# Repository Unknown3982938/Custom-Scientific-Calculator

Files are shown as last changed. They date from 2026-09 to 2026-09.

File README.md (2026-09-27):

# Custom-Scientific-Calculator
An open-source custom scientific calculator based on an ESP32, featuring a dedicated keypad matrix, MCP23017 I/O expansion, ST7789 display, rechargeable Li-ion power system, and a custom PCB.

# Project Status
## Work-In-Progress (WIP)
The hardware is currently undergoing PCB and mechanical development. Firmware and enclosure designs are also under active development and may change as physical prototypes are assembled and tested.

# Features
- ESP32-based controller
- ST7789 Color TFT (2.8 inch)
- MCP23017 I/O Expander
- 45 key Physical key matrix (custom)
- SD card support(OPTIONAL)
- Scientific and mathematical functions
- Rechargeable battery
- Modular/Serviceable design (planned to make a compact version, consisting of SMTs instead of THTs)
- Custom PCB
- Custom enclosure

# Repository Contents
- HARDWARE/ - Schematic, BOM, and PCB layout
- FIRMWARE/ - Sketch Code and other software related contents
- CAD/ENCLOSURE/ - Enclosure and Mechanical CAD files
- Manufacturing/ - fabrication-ready manufacturing files
- REFERENCES - Additional materials and information (e.g. Simulations, tests, and additional datas)

# Hardware
The calculator uses a custom PCB designed specifically for the project. The hardware is still being refined and has not yet completed final physical validation.

# Firmware
Firmware development is currently in progress. The included firmware represents the current development state and is subject to change as the hardware is validated.

# CAD
The enclosure and other mechanical components are included as CAD files. These designs are still being refined alongside the PCB and physical prototype.

# Goals
The goal is to create a functional, portable scientific calculator while gaining practical experience in:
- PCB design
- Embedded programming
- Human-machine interfaces
- Power management
- Mechanical design
- Electronics Manufacturing

---

The project is being developed incrementally, with hardware and software tested as each subsystem is completed.

ova
schem
Screenshot from 2026-09-11 13-05-26

---

# Socials:
(for other projects that is currently independently developed)

- https://tiktok.com/@philie_imation_001 (TIKTOK account)
- (some are set to private for now)

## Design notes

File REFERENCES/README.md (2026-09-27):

# REFERENCES:
## Circuit simulation:
- https://app.cirkitdesigner.com/project/ea1d36da-37de-4177-8c43-86d26a5ac79b (unfinished)

## Keymaps
- (TBA)

## GUI design
- (TBA)

---

TikTok acc: https://tiktok.com/@philie_imation_001 (this is where I often share my projects)

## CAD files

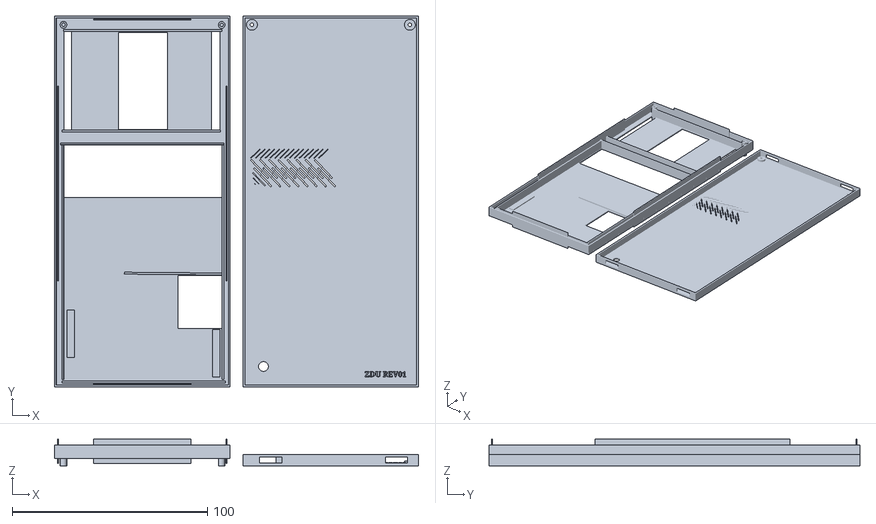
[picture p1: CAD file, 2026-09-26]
CAD/ENCLOSURE/custom cal enclosure(bottom)(1).stl
186.6 x 190.0 x 13.8

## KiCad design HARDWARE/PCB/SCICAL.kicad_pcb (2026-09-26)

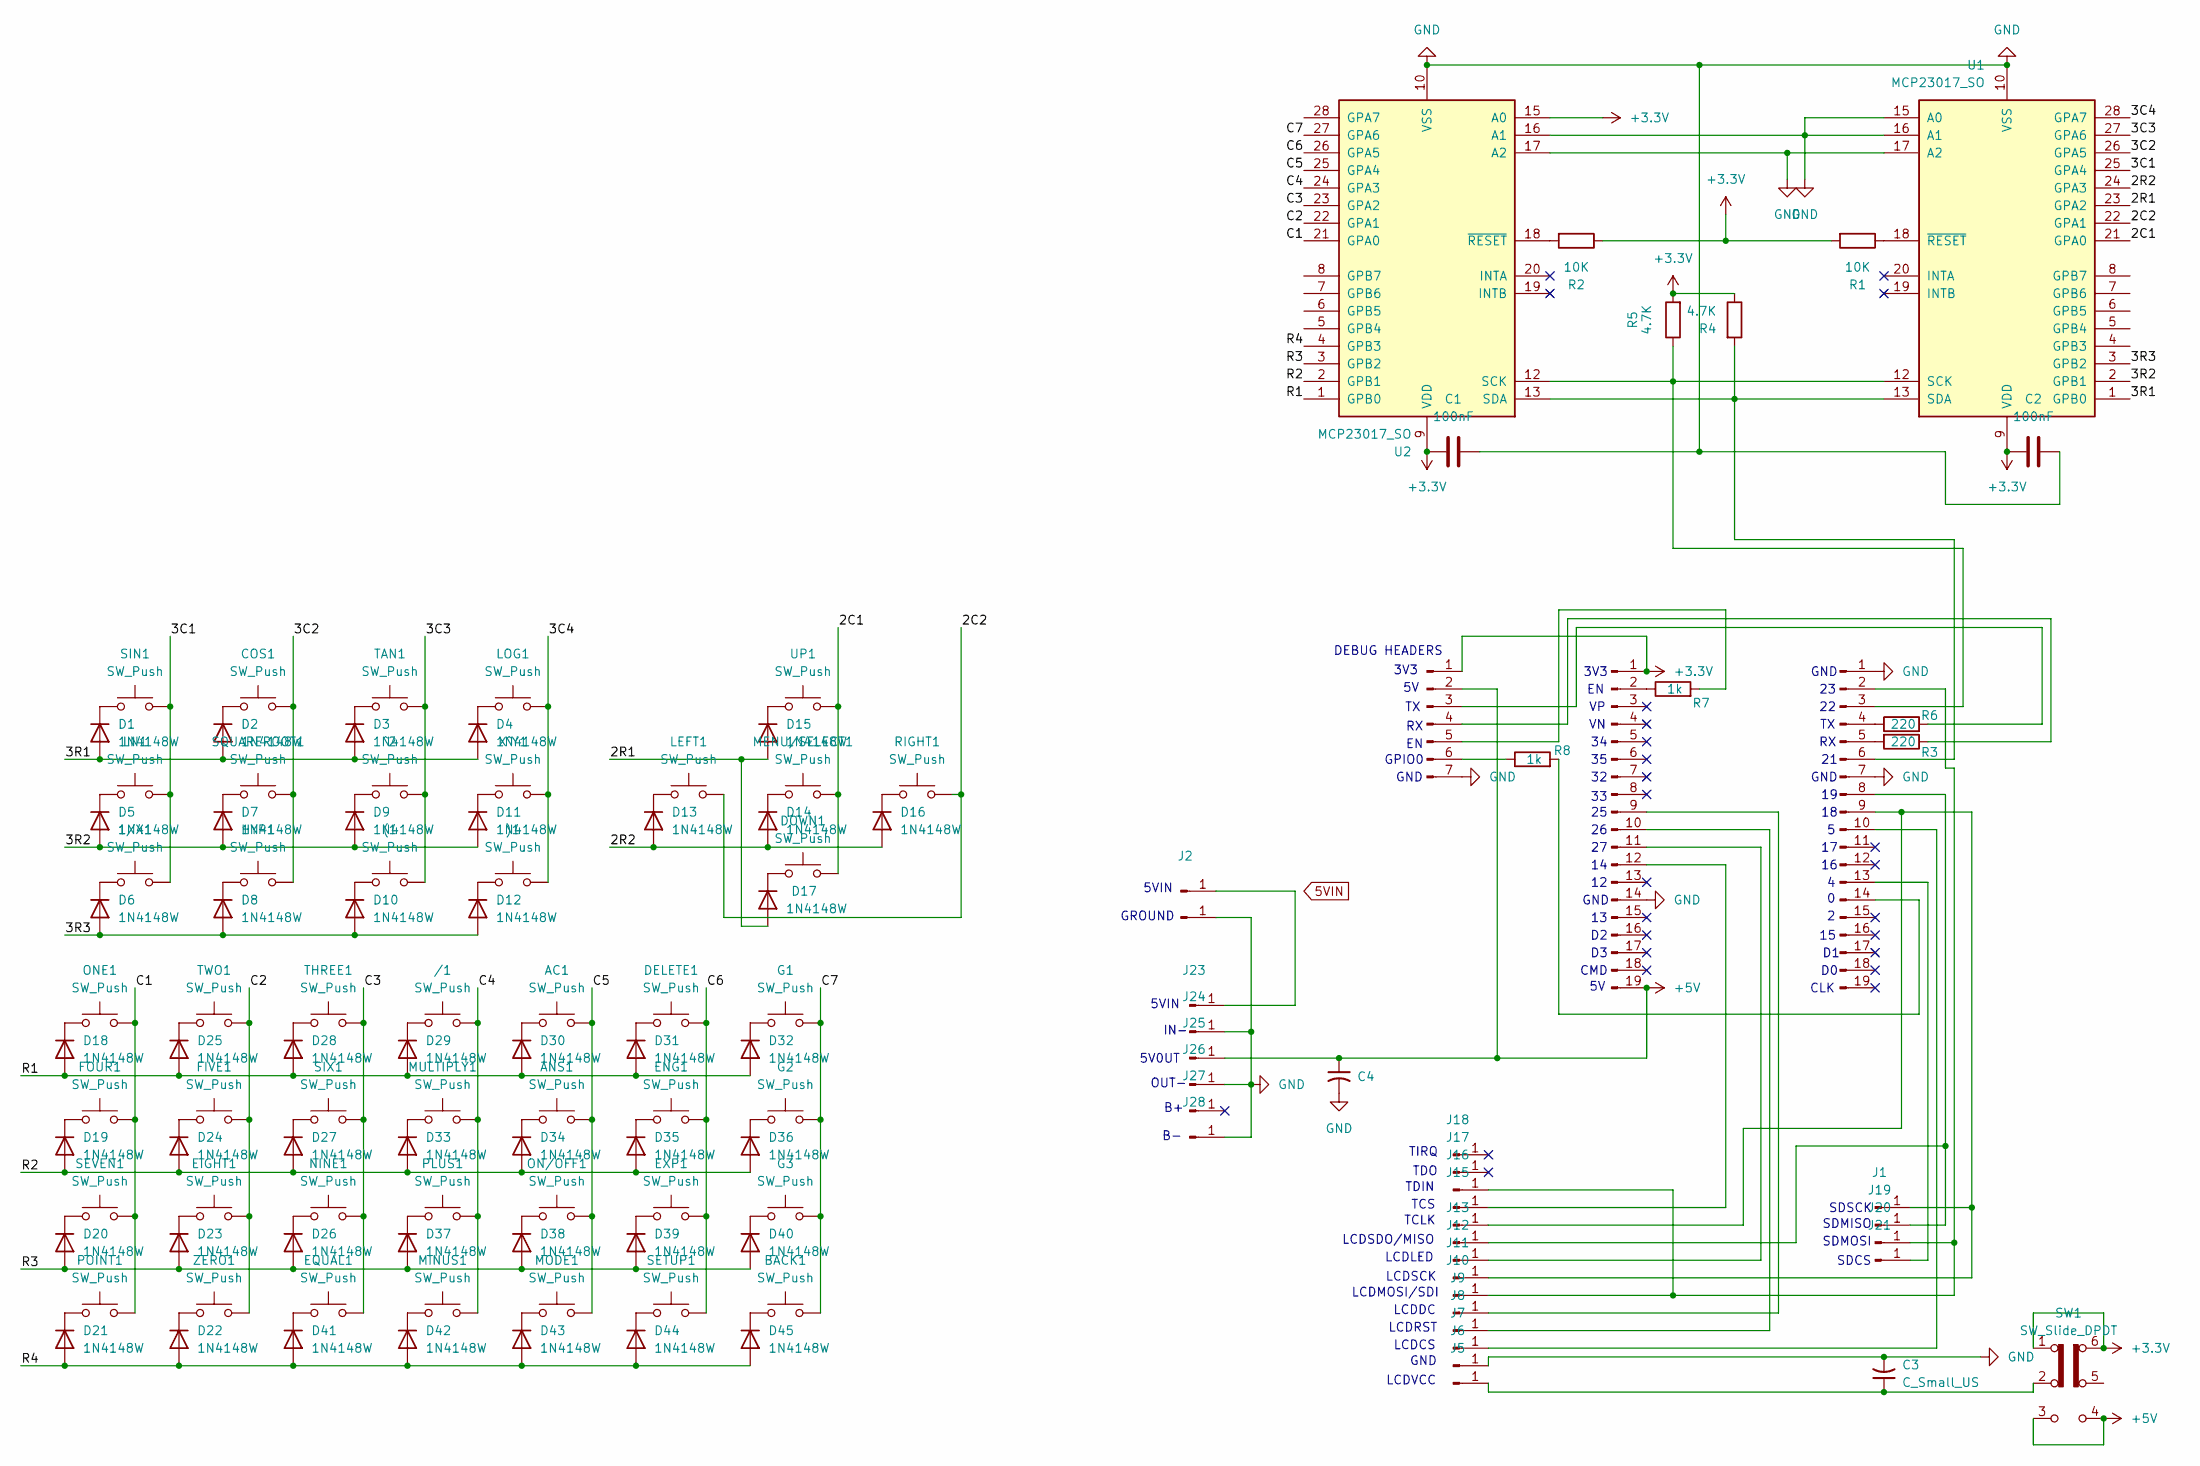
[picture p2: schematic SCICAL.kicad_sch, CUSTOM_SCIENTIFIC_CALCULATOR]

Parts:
1/X1: SW_Push; SW_PUSH_6mm
(1: SW_Push; SW_PUSH_6mm
)1: SW_Push; SW_PUSH_6mm
/1: SW_Push; SW_PUSH_6mm
AC1: SW_Push; SW_PUSH_6mm
ANS1: SW_Push; SW_PUSH_6mm
BACK1: SW_Push; SW_PUSH_6mm
C1, C2: 100nF; C_Disc_D3.0mm_W1.6mm_P2.50mm
C3: C_Small_US; C_Radial_D4.0mm_H5.0mm_P1.50mm
C4: C_Small_US; C_Radial_D5.0mm_H11.0mm_P2.00mm
COS1: SW_Push; SW_PUSH_6mm
D1, D2, D3, D4, D5, D6, D7, D8, D9, D10, D11, D12, D13, D14, D15, D16, D17, D18, D19, D20, D21, D22, D23, D24, D25, D26, D27, D28, D29, D30, D31, D32, D33, D34, D35, D36, D37, D38, D39, D40, D41, D42, D43, D44, D45: 1N4148W; D_DO-35_SOD27_P7.62mm_Horizontal
DELETE1: SW_Push; SW_PUSH_6mm
DOWN1: SW_Push; SW_PUSH_6mm
EIGHT1: SW_Push; SW_PUSH_6mm
ENG1: SW_Push; SW_PUSH_6mm
EQUAL1: SW_Push; SW_PUSH_6mm
EXP1: SW_Push; SW_PUSH_6mm
FIVE1: SW_Push; SW_PUSH_6mm
FOUR1: SW_Push; SW_PUSH_6mm
G1, G2, G3: SW_Push; SW_PUSH_6mm
HYP1: SW_Push; SW_PUSH_6mm
J1, J2, J5, J6, J7, J8, J9, J10, J11, J12, J13, J14, J15, J16, J17, J18, J19, J20, J21, J22: Conn_01x01_Pin; SolderWirePad_1x01_SMD_1x2mm
J3, J4: Conn_01x19_Pin; PinHeader_1x19_P2.54mm_Vertical
J23, J24, J25, J26, J27, J28: Conn_01x01_Pin; TestPoint_Pad_2.0x2.0mm
J30: Conn_01x07_Pin; PinHeader_1x07_P2.54mm_Vertical
LEFT1: SW_Push; SW_PUSH_6mm
LN1: SW_Push; SW_PUSH_6mm
LOG1: SW_Push; SW_PUSH_6mm
MENU/SELECT1: SW_Push; SW_PUSH_6mm
MINUS1: SW_Push; SW_PUSH_6mm
MODE1: SW_Push; SW_PUSH_6mm
MULTIPLY1: SW_Push; SW_PUSH_6mm
NINE1: SW_Push; SW_PUSH_6mm
ON/OFF1: SW_Push; SW_PUSH_6mm
ONE1: SW_Push; SW_PUSH_6mm
PLUS1: SW_Push; SW_PUSH_6mm
POINT1: SW_Push; SW_PUSH_6mm
R1, R2: 10K; R_Axial_DIN0207_L6.3mm_D2.5mm_P10.16mm_Horizontal
R3, R6: 220; R_Axial_DIN0207_L6.3mm_D2.5mm_P10.16mm_Horizontal
R4, R5: 4.7K; R_Axial_DIN0207_L6.3mm_D2.5mm_P10.16mm_Horizontal
R7, R8: 1k; R_Axial_DIN0207_L6.3mm_D2.5mm_P10.16mm_Horizontal
RIGHT1: SW_Push; SW_PUSH_6mm
SETUP1: SW_Push; SW_PUSH_6mm
SEVEN1: SW_Push; SW_PUSH_6mm
SIN1: SW_Push; SW_PUSH_6mm
SIX1: SW_Push; SW_PUSH_6mm
SQUAREROOT1: SW_Push; SW_PUSH_6mm
SW1: SW_Slide_DPDT; SW_CK_JS202011CQN_DPDT_Straight
TAN1: SW_Push; SW_PUSH_6mm
THREE1: SW_Push; SW_PUSH_6mm
TWO1: SW_Push; SW_PUSH_6mm
U1, U2: MCP23017_SO; SOIC-28W_7.5x17.9mm_P1.27mm
UP1: SW_Push; SW_PUSH_6mm
X^Y1: SW_Push; SW_PUSH_6mm
ZERO1: SW_Push; SW_PUSH_6mm
^2: SW_Push; SW_PUSH_6mm

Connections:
+3.3V: C1.1, C2.2, J3.1, J30.1, R1.2, R2.1, R4.1, R5.2, SW1.1 (A), SW1.6 (C), U1.9 (VDD), U2.9 (VDD), U2.15 (A0)
+5V: C4.1, J3.19, J25.1, J30.2, SW1.3 (C), SW1.4 (A)
/2C1: DOWN1.2, MENU/SELECT1.2, U1.21 (GPA0), UP1.2
/2C2: LEFT1.2, RIGHT1.2, U1.22 (GPA1)
/2R1: D15.2 (A), D17.2 (A), U1.23 (GPA2)
/2R2: D13.2 (A), D14.2 (A), D16.2 (A), U1.24 (GPA3)
/3C1: 1/X1.2, LN1.2, SIN1.2, U1.25 (GPA4)
/3C2: COS1.2, HYP1.2, SQUAREROOT1.2, U1.26 (GPA5)
/3C3: (1.2, TAN1.2, U1.27 (GPA6), ^2.2
/3C4: )1.2, LOG1.2, U1.28 (GPA7), X^Y1.2
/3R1: D1.2 (A), D2.2 (A), D3.2 (A), D4.2 (A), U1.1 (GPB0)
/3R2: D5.2 (A), D7.2 (A), D9.2 (A), D11.2 (A), U1.2 (GPB1)
/3R3: D6.2 (A), D8.2 (A), D10.2 (A), D12.2 (A), U1.3 (GPB2)
/C1: FOUR1.2, ONE1.2, POINT1.2, SEVEN1.2, U2.21 (GPA0)
/C2: EIGHT1.2, FIVE1.2, TWO1.2, U2.22 (GPA1), ZERO1.2
/C3: EQUAL1.2, NINE1.2, SIX1.2, THREE1.2, U2.23 (GPA2)
/C4: /1.2, MINUS1.2, MULTIPLY1.2, PLUS1.2, U2.24 (GPA3)
/C5: AC1.2, ANS1.2, MODE1.2, ON/OFF1.2, U2.25 (GPA4)
/C6: DELETE1.2, ENG1.2, EXP1.2, SETUP1.2, U2.26 (GPA5)
/C7: BACK1.2, G1.2, G2.2, G3.2, U2.27 (GPA6)
/R1: D18.2 (A), D25.2 (A), D28.2 (A), D29.2 (A), D30.2 (A), D31.2 (A), D32.2 (A), U2.1 (GPB0)
/R2: D19.2 (A), D24.2 (A), D27.2 (A), D33.2 (A), D34.2 (A), D35.2 (A), D36.2 (A), U2.2 (GPB1)
/R3: D20.2 (A), D23.2 (A), D26.2 (A), D37.2 (A), D38.2 (A), D39.2 (A), D40.2 (A), U2.3 (GPB2)
/R4: D21.2 (A), D22.2 (A), D41.2 (A), D42.2 (A), D43.2 (A), D44.2 (A), D45.2 (A), U2.4 (GPB3)
GND: C1.2, C2.1, C3.2, C4.2, J3.14, J4.1, J4.7, J6.1, J22.1, J24.1, J26.1, J28.1, J30.7, U1.10 (VSS), U1.15 (A0), U1.16 (A1), U1.17 (A2), U2.10 (VSS), U2.16 (A1), U2.17 (A2)
unnamed: D1.1 (K), SIN1.1
unnamed: COS1.1, D2.1 (K)
unnamed: D3.1 (K), TAN1.1
unnamed: D4.1 (K), LOG1.1
unnamed: D5.1 (K), LN1.1
unnamed: 1/X1.1, D6.1 (K)
unnamed: D7.1 (K), SQUAREROOT1.1
unnamed: D8.1 (K), HYP1.1
unnamed: D9.1 (K), ^2.1
unnamed: (1.1, D10.1 (K)
unnamed: D11.1 (K), X^Y1.1
unnamed: )1.1, D12.1 (K)
unnamed: D13.1 (K), LEFT1.1
unnamed: D14.1 (K), MENU/SELECT1.1
unnamed: D15.1 (K), UP1.1
unnamed: D16.1 (K), RIGHT1.1
unnamed: D17.1 (K), DOWN1.1
unnamed: D18.1 (K), ONE1.1
unnamed: D19.1 (K), FOUR1.1
unnamed: D20.1 (K), SEVEN1.1
unnamed: D21.1 (K), POINT1.1
unnamed: D22.1 (K), ZERO1.1
unnamed: D23.1 (K), EIGHT1.1
unnamed: D24.1 (K), FIVE1.1
unnamed: D25.1 (K), TWO1.1
unnamed: D26.1 (K), NINE1.1
unnamed: D27.1 (K), SIX1.1
unnamed: D28.1 (K), THREE1.1
unnamed: /1.1, D29.1 (K)
unnamed: AC1.1, D30.1 (K)
unnamed: D31.1 (K), DELETE1.1
unnamed: D32.1 (K), G1.1
unnamed: D33.1 (K), MULTIPLY1.1
unnamed: ANS1.1, D34.1 (K)
unnamed: D35.1 (K), ENG1.1
unnamed: D36.1 (K), G2.1
unnamed: D37.1 (K), PLUS1.1
unnamed: D38.1 (K), ON/OFF1.1
unnamed: D39.1 (K), EXP1.1
unnamed: D40.1 (K), G3.1
unnamed: D41.1 (K), EQUAL1.1
unnamed: D42.1 (K), MINUS1.1
unnamed: D43.1 (K), MODE1.1
unnamed: D44.1 (K), SETUP1.1
unnamed: BACK1.1, D45.1 (K)
unnamed: J1.1, J4.9, J11.1, J14.1
unnamed: J2.1, J23.1
unnamed: J3.2, R7.1
unnamed: J3.9, J9.1
unnamed: J3.10, J8.1
unnamed: J4.3, R5.1, U1.12 (SCK), U2.12 (SCK)
unnamed: J4.4, R6.1
unnamed: J4.5, R3.2
unnamed: J4.6, R4.2, U1.13 (SDA), U2.13 (SDA)
unnamed: J4.10, J7.1
unnamed: J4.14, R8.2
unnamed: C3.1, J5.1, SW1.2 (B)
unnamed: J4.2, J10.1, J16.1, J20.1
unnamed: J3.11, J12.1
unnamed: J4.8, J13.1, J19.1
unnamed: J3.12, J15.1
unnamed: J4.13, J21.1
unnamed: J30.3, R6.2
unnamed: J30.4, R3.1
unnamed: J30.5, R7.2
unnamed: J30.6, R8.1
unnamed: R1.1, U1.18 (~RESET)
unnamed: R2.2, U2.18 (~RESET)

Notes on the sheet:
GPIO0
SDCS
5V0UT
TCS
LCDLED
SDSCK
LCDSCK
SDMISO
CMD
SDMOSI
DEBUG HEADERS
TDO
TCLK
3V3
IN-
LCDMOSI/SDI
LCDCS
LCDSDO/MISO
CLK
GND
OUT-
GROUND
5VIN
LCDDC
LCDVCC
LCDRST
TIRQ
TDIN
5VIN

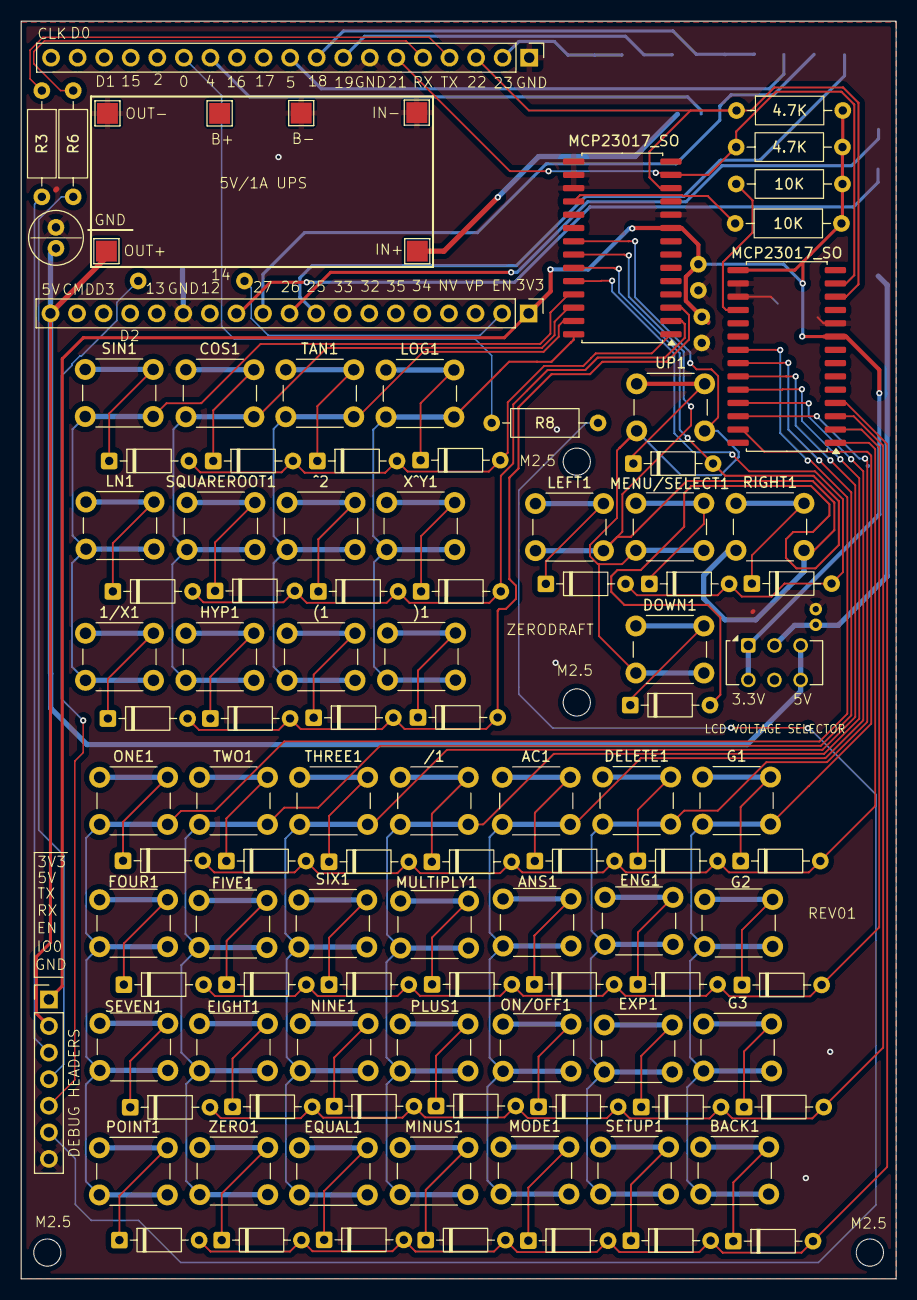
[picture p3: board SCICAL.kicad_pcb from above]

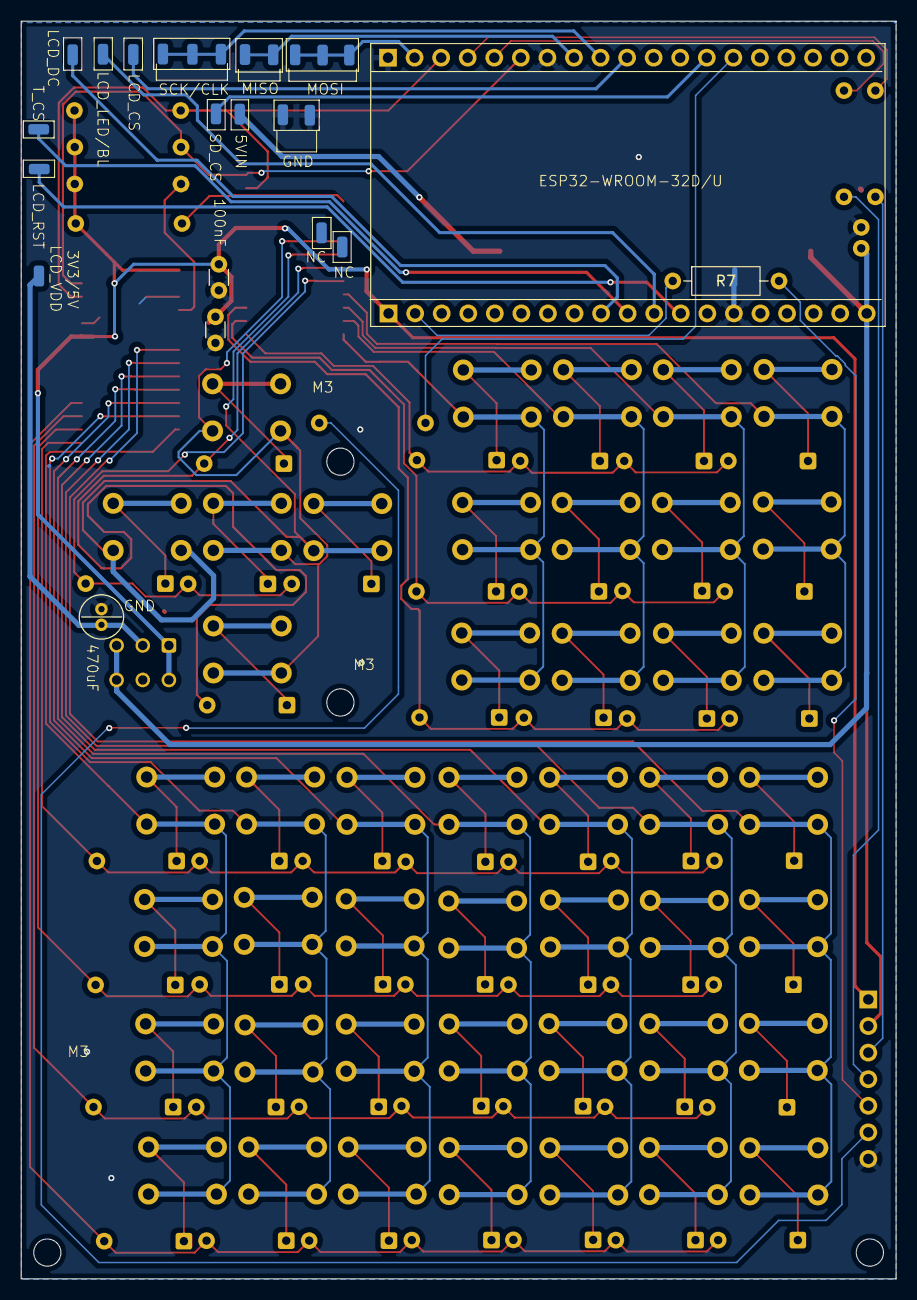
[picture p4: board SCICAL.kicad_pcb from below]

Board: 2 copper layers, 83.7 x 120.2 mm, 134 parts (24 on the bottom side), 93 nets.

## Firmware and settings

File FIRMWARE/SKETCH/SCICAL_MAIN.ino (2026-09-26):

// Status: Under development
#include <Wire.h>
#include <Adafruit_GFX.h>
#include <Adafruit_ST7789.h>

#define I2C_SDA 21
#define I2C_SCL 22
#define MCP1_ADDR 0x20
#define MCP2_ADDR 0x21
#define TFT_CS   5
#define TFT_DC   25
#define TFT_RST  26
#define TFT_BL   27

Adafruit_ST7789 tft(TFT_CS, TFT_DC, TFT_RST);

// The exact matrix scanning implementation can be filled in after the final PCB pin mapping is confirmed.

String inputBuffer = "";
String resultBuffer = "";

bool calculatorOn = true;

void mcpWrite(uint8_t address, uint8_t reg, uint8_t value)
{
    Wire.beginTransmission(address);
    Wire.write(reg);
    Wire.write(value);
    Wire.endTransmission();
}

uint8_t mcpRead(uint8_t address, uint8_t reg)
{
    Wire.beginTransmission(address);
    Wire.write(reg);
    Wire.endTransmission();

    Wire.requestFrom(address, (uint8_t)1);

    if (Wire.available())
        return Wire.read();

    return 0;
}

void initMCP23017(uint8_t address)
{
  
    mcpWrite(address, 0x00, 0xFF);
    mcpWrite(address, 0x01, 0xFF);

    mcpWrite(address, 0x0C, 0xFF);
    mcpWrite(address, 0x0D, 0xFF); 
}

void initDisplay()
{
    pinMode(TFT_BL, OUTPUT);
    digitalWrite(TFT_BL, HIGH);

    tft.init(240, 320);
    tft.setRotation(1);

    tft.fillScreen(ST77XX_BLACK);

    tft.setTextColor(ST77XX_WHITE);
    tft.setTextSize(2);

    tft.setCursor(10, 10);
    tft.println("Scientific Calculator");

    tft.setCursor(10, 40);
    tft.println("Firmware WIP");
}

void updateDisplay()
{
    tft.fillScreen(ST77XX_BLACK);
    tft.setTextColor(ST77XX_WHITE);
    tft.setTextSize(2);
    tft.setCursor(10, 20);
    tft.println(inputBuffer);
    tft.setCursor(10, 70);
    tft.println(resultBuffer);
}

void handleKey(char key)
{
    switch (key)
    {
        case '0':
        case '1':
        case '2':
        case '3':
        case '4':
        case '5':
        case '6':
        case '7':
        case '8':
        case '9':
        case '.':
            inputBuffer += key;
            break;

        case '+':
        case '-':
        case '*':
        case '/':
            inputBuffer += key;
            break;

        case '=':
            resultBuffer = "TODO";
            break;

        case 'C':
            inputBuffer = "";
            resultBuffer = "";
            break;

        default:
            break;
    }

    updateDisplay();
}


void scanMatrix()
{
     /* TODO list:
     * 1. Configure one matrix row as active.
     * 2. Read the column inputs.
     * 3. Determine which key is pressed.
     * 4. Debounce the key.
     * 5. Convert the matrix position into a calculator key.
     * (The final implementation should use the actual
     * MCP23017 pin assignments from the PCB)
     */
}

void setup()
{
    Serial.begin(115200);

    Wire.begin(I2C_SDA, I2C_SCL);

    Serial.println();
    Serial.println("Custom Scientific Calculator");
    Serial.println("Firmware WIP");

    initMCP23017(MCP1_ADDR);
    initMCP23017(MCP2_ADDR);

    initDisplay();

    Serial.println("Initialization complete. Confirm function");
}


void loop()
{
    scanMatrix();

    // Future:
    // - Key debounce
    // - Calculator expression parser
    // - Scientific functions
    // - Angle modes
    // - Memory functions
    // - SD card functionality
    // - Touchscreen UI
    // - Power management

    delay(5);
}

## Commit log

2026-09-11 Add project notes for PCB and 3D printing plans
2026-09-27 Update README with references and TikTok account
    Added references for circuit simulation, keymaps, and GUI design.
2026-09-27 Update README to include REFERENCES section
    Added a section for additional materials and information.
